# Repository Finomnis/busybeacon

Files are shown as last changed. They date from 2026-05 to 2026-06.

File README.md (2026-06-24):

# BusyBeacon

<p>
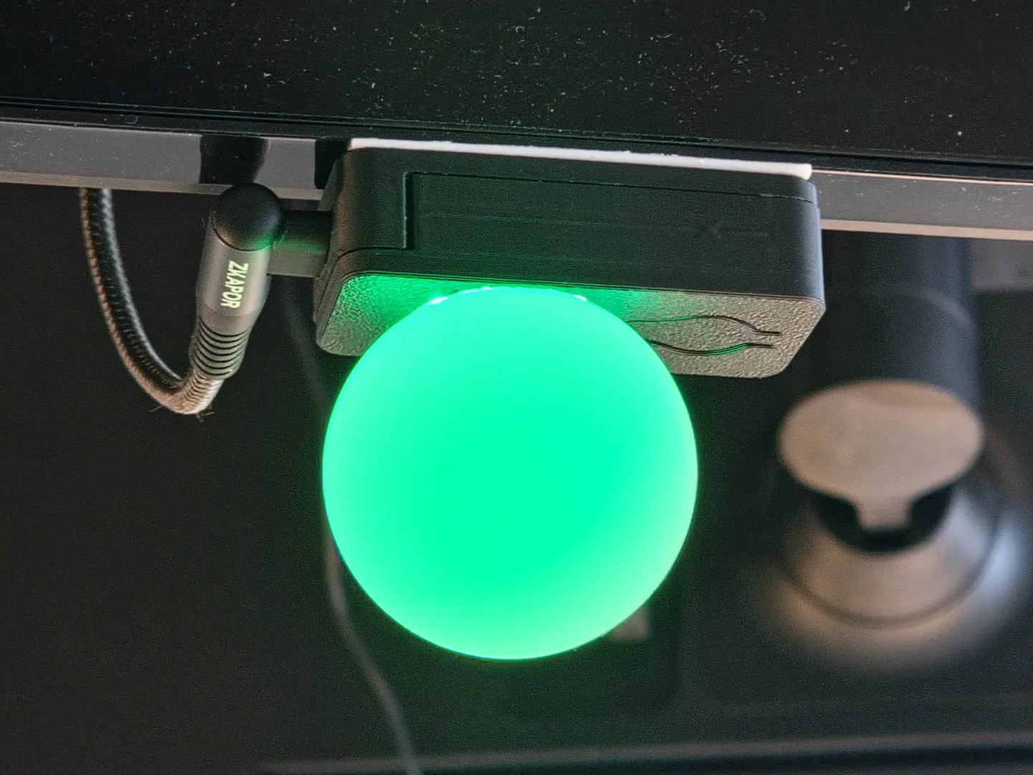
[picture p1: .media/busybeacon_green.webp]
Green

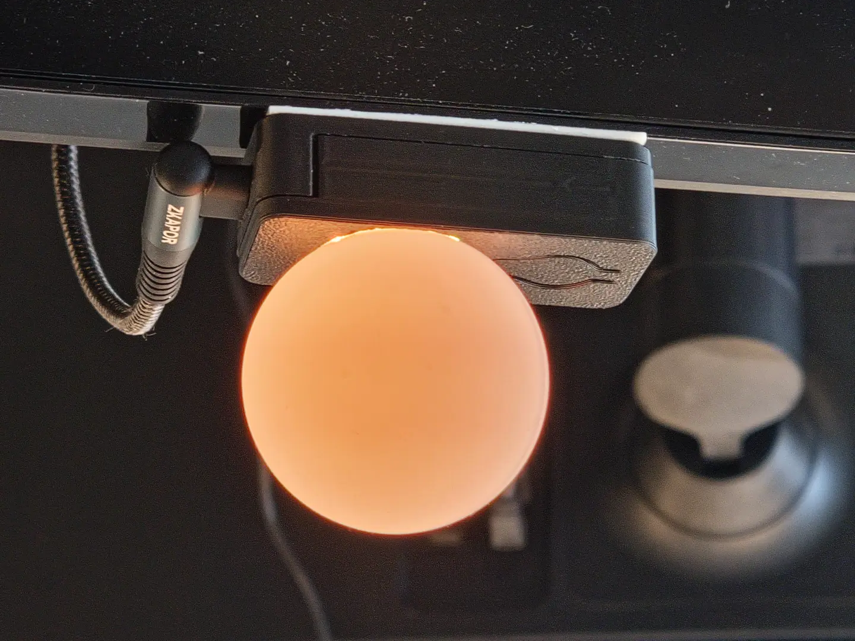
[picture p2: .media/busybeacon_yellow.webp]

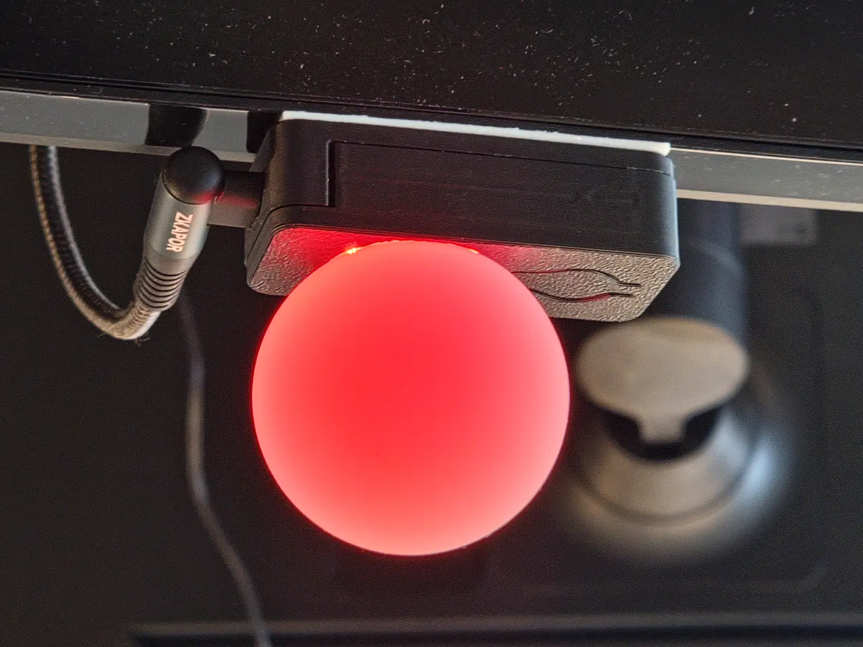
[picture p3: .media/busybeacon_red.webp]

</p>

An indicator that shows coworkers if you are busy.

Intended to be mounted to your monitor and updated whenever your current state changes.

### Color Meanings
- 🟢 **Green** - Can be talked to casually.
- 🟡 **Yellow** - Concentrated, only talk to about the current project.
- 🔴 **Red** - In the zone, do not talk to unless absolutely necessary.

### Controls

- Button:
    - Short press: Switch between colors
    - Long press: Turn on/off
- USB:
    - USB-HID device that can be used to set the color and switch it on/off
    - Turns off when the USB data connection stops (e.g. the PC is shut down).
        - Intended for monitors that power the device constantly, even if the PC is off

## Parts

- Table Tennis Ball as light diffusor
    - For best experience, choose seamless balls
- [Custom PCB](https://oshwlab.com/finomnis/busylight)
    - Orderable on JLCPCB for ~60 Euros / 10 PCBs
- 3D Printed Case
- LEDs: BTF-LIGHTING 144LEDs/m WS2812B
    - German Amazon: https://amzn.eu/d/06CgZDho
    - 3 LEDs needed per device

## Host software

The device can be controlled from the PC using the following programs:

- `busybeacon` - A tray icon with a menu
- `busybeacon-cli` - A command line tool

For Windows, precompiled executables can be found in the [releases page](https://github.com/Finomnis/busybeacon/releases).

- Copy `busybeacon.exe` into `%APPDATA%\Microsoft\Windows\Start Menu\Programs\Startup` to start it automatically on bootup.
- Once it runs, right click on taskbar -> `Taskbar settings` -> `Other system tray icons` -> `busybeacon.exe` -> `On` to show it in the taskbar

For Linux / MacOS, the `software` directory contains the source code
that can be compiled as usual:

```shell
cd software
cargo build --release
```

MacOS is currently untested.

## Firmware

The newest version can be found in the [releases page](https://github.com/Finomnis/busybeacon/releases).

The bootloader and firmware have to be installed once from the `.hex` files:

```shell
probe-rs download --binary-format hex --chip stm32u073cc --verify busybeacon.bootloader.hex
probe-rs download --binary-format hex --chip stm32u073cc --verify busybeacon.hex
```

Afterwards, the application can be updated via the `.dfu` file:

```shell
dfu-util --download busybeacon.dfu
```

If DFU flashing fails, enter bootloader recovery mode by keeping the button pressed while plugging in the device. It should then react to `dfu-util` again.

**NOTE:** It is normal that `dfu-util` ends with an error message like so:
```
Download        [=========================] 100%        90672 bytes
Download done.
dfu-util: unable to read DFU status after completion (LIBUSB_ERROR_IO)
```

This is a technical limitation that might get fixed in the future, but it's purely cosmetic.

## Build Instructions

1. Download the relevant files from the [releases page](https://github.com/Finomnis/busybeacon/releases).
2. Flash the PCB with the latest bootloader & firmware.
   - This requires a TC2050 adapter and a suitable probe.
   - For more information, see `Firmware` in this readme.
3. Print the case (top and bot)
4. Cut 3 LEDs from your BTF-LIGHTING 144LEDs/m WS2812B strip
5. Connect the PCB and the LEDs with three wires
6. Insert the PCB into the bottom case and glue the LED strip on the little
   shelf that will face the ball
7. Cut a hole in your tennis ball that fits the three LEDs
8. Glue the Ball on the Top case
9. Slide the case together

Then, plug the device into a USB-C port and you will see the ball light up green.

You can now control the ball using the button as described in the `Controls` section, or you can install the tray icon app to control it via a tray icon of your PC.

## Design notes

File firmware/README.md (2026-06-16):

# BusyBeacon Firmware

## Datasheets:

- [STM32U073CCU6 Datasheet](https://www.st.com/resource/en/datasheet/stm32u073cc.pdf)
- [STM32U0 Reference Manual](https://www.st.com/resource/en/reference_manual/rm0503-stm32u0-series-advanced-armbased-32bit-mcus-stmicroelectronics.pdf)

## Getting Started

Before getting started, you need Rust/Cargo installed.

See https://rustup.rs/.

### Further dependencies

- `cargo binstall` - Optional, if not desired replace `binstall` in the other dependencies with `install`

  ```shell
  cargo install cargo-binstall --locked
  ```

- `flip-link`

  ```shell
  cargo binstall flip-link
  ```

- `cargo objcopy`

  ```
  rustup component add llvm-tools
  cargo binstall cargo-binutils
  ```

- `probe-rs`

  ```
  cargo binstall probe-rs-tools
  ```

## Application

### Build

```shell
cargo build --release
```

### Build and flash

```shell
cargo program --release
```

### Generate hex

```shell
cargo objcopy --release -- -O ihex app.hex

# To flash:
probe-rs download --binary-format hex --chip stm32u073cc app.hex
```

### Generate dfu file

```shell
cargo objcopy --release -- -O binary app.dfu
# Add dfu suffix containing VID:PID to the image:
dfu-suffix --vid 1209 --pid d9d0 --add app.dfu

# To update:
sudo dfu-util --download app.dfu
```

*Note*: It is normal to get the following error at the end of the update.
This is currently a technical limitation, but it's purely cosmetic.

```text
...
Download done.
unable to read DFU status after completion (LIBUSB_ERROR_PIPE)
```

## Bootloader

### Build

```shell
cargo build -p busybeacon-bootloader --release
```

### Build and flash

```shell
cargo program -p busybeacon-bootloader --release
```

### Generate hex

```shell
cargo objcopy -p busybeacon-bootloader --release -- -O ihex bootloader.hex

# To flash:
probe-rs download --binary-format hex --chip stm32u073cc bootloader.hex
```

## Tests

### Execute tests on host

```shell
cargo test-host
```

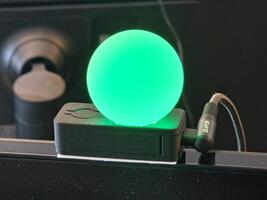
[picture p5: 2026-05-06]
.media/busybeacon_green_small.jpg

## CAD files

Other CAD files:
hardware/BusyBeaconCase_Bot.step
hardware/BusyBeaconCase_Top.step
hardware/BusyBeaconCase.f3z

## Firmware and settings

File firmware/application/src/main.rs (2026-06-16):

#![no_std]
#![no_main]

mod led_statemachine;
mod panic_handler;
mod uart_logger;
mod usb_utils;

use async_button_rtic::{Button, ButtonConfig, ButtonEvent};
use core::cell::RefCell;
use embassy_boot_stm32::{AlignedBuffer, BlockingFirmwareState, FirmwareUpdaterConfig};
use embassy_stm32::{
    Config, bind_interrupts, dma,
    exti::{self, ExtiInput},
    flash::{Flash, WRITE_SIZE},
    gpio::Pull,
    interrupt,
    mode::Async,
    peripherals,
    rcc::mux::Clk48sel,
    spi,
    spi::Spi,
    time::Hertz,
    usart, usb,
};
use embassy_usb::{
    UsbDevice,
    class::hid::{self, HidBootProtocol, HidReader, HidSubclass, HidWriter},
    msos,
};
use embassy_usb_dfu::application::{DfuAttributes, DfuState, usb_dfu};
use led_statemachine::{LedController, LedEvent};
use log::info;
use portable_atomic::AtomicU8;
use static_cell::ConstStaticCell;
use usb_utils::{
    DEVICE_INTERFACE_GUIDS, HidRequestHandler, USB_BCD_DEVICE_VERSION, UsbEventHandler,
};

bind_interrupts!(struct Irqs {
    DMA1_CHANNEL2_3 =>
        dma::InterruptHandler<peripherals::DMA1_CH2>,
        dma::InterruptHandler<peripherals::DMA1_CH3>;
    EXTI4_15 => exti::InterruptHandler<interrupt::typelevel::EXTI4_15>;
    USB_DRD_FS => usb::InterruptHandler<peripherals::USB>;
});

struct DfuHandler<'d, FLASH: embedded_storage::nor_flash::NorFlash> {
    firmware_state: BlockingFirmwareState<'d, FLASH>,
}

impl<FLASH: embedded_storage::nor_flash::NorFlash> embassy_usb_dfu::application::Handler
    for DfuHandler<'_, FLASH>
{
    fn enter_dfu(&mut self) {
        match self.firmware_state.mark_dfu() {
            Ok(()) => cortex_m::peripheral::SCB::sys_reset(),
            Err(_) => {
                log::error!("failed to mark DFU mode");
            }
        }
    }
}

static CONFIG_DESCRIPTOR: ConstStaticCell<[u8; 256]> = ConstStaticCell::new([0u8; 256]);
static BOS_DESCRIPTOR: ConstStaticCell<[u8; 256]> = ConstStaticCell::new([0u8; 256]);
static MSOS_DESCRIPTOR: ConstStaticCell<[u8; 1024]> = ConstStaticCell::new([0u8; 1024]);
static CONTROL_BUF: ConstStaticCell<[u8; 4096]> = ConstStaticCell::new([0u8; 4096]);
static MAGIC: ConstStaticCell<embassy_boot_stm32::AlignedBuffer<WRITE_SIZE>> =
    ConstStaticCell::new(AlignedBuffer([0; WRITE_SIZE]));

use rtic_monotonics::stm32::prelude::*;
stm32_tim2_monotonic!(Mono, 1_000_000);

type BlockingFlash = Flash<'static, embassy_stm32::flash::Blocking>;

const HID_REPORT_DESCRIPTOR: &[u8] = &[
    0x06, 0x00, 0xff, // Usage Page: vendor-defined 0xff00
    0x09, 0x01, // Usage: 1
    0xa1, 0x01, // Collection: Application
    //
    // Output report: 1 byte, values 0..3.
    0x85, 0x01, // Report ID 1
    0x09, 0x01, // Usage: busy state
    0x15, 0x00, // Logical min 0
    0x25, 0x03, // Logical max 3
    0x75, 0x08, // Report size 8 bits
    0x95, 0x01, // Report count 1
    0x91, 0x02, // Output: Data,Var,Abs
    //
    // Feature report: PC queries current LED state
    0x85, 0x02, // Report ID 2
    0x09, 0x02, //
    0x15, 0x00, //
    0x25, 0x03, //
    0x75, 0x08, //
    0x95, 0x01, //
    0xb1, 0x02, // Feature
    //
    // Input report: device pushes current LED state
    0x85, 0x03, // Report ID 3
    0x09, 0x03, //
    0x15, 0x00, //
    0x25, 0x03, //
    0x75, 0x08, //
    0x95, 0x01, //
    0x81, 0x02, // Input
    //
    0xc0, // End collection
];

static LED_STATE: AtomicU8 = AtomicU8::new(0);

#[rtic::app(
    device = ::embassy_stm32::pac,
    peripherals = false,
    dispatchers = [TIM15_LPTIM3, TIM16, TIM7_LPTIM2] // free IRQs used by RTIC for async software tasks
)]
mod app {

    use super::*;

    #[shared]
    struct Shared {
        led_event_sender: rtic_sync::channel::Sender<'static, LedEvent, 10>,
    }

    #[local]
    struct Local {
        led_controller: LedController,
        button: Button<ExtiInput<'static, Async>, Mono>,
        log_handler: uart_logger::UartLogHandler,
        usb_dev: UsbDevice<'static, usb::Driver<'static, peripherals::USB>>,
        hid_reader: HidReader<'static, usb::Driver<'static, peripherals::USB>, 8>,
        hid_writer: HidWriter<'static, usb::Driver<'static, peripherals::USB>, 8>,
        state_changed_writer: rtic_sync::signal::SignalWriter<'static, u8>,
        state_changed_reader: rtic_sync::signal::SignalReader<'static, u8>,
    }

    #[init(local = [
        flash: Option<embassy_sync::blocking_mutex::NoopMutex<RefCell<BlockingFlash>>> = None,
        dfu_state: Option<DfuState<DfuHandler<'static, embassy_embedded_hal::flash::partition::BlockingPartition<'static, embassy_sync::blocking_mutex::raw::NoopRawMutex, BlockingFlash>>>> = None,
        hid_state: Option<hid::State<'static>> = None,
        usb_event_handler: Option<UsbEventHandler> = None,
        hid_request_handler: HidRequestHandler = HidRequestHandler::new(),
    ])]
    fn init(mut cx: init::Context) -> (Shared, Local) {
        let mut config = Config::default();
        {
            use embassy_stm32::rcc::*;
            config.rcc.hsi = true;
            config.rcc.pll = Some(Pll {
                source: PllSource::HSI, // 16 MHz
                prediv: PllPreDiv::DIV1,
                mul: PllMul::MUL6, // 16 * 6 = 96 MHz
                divp: None,
                divq: None,
                divr: Some(PllRDiv::DIV2), // 96 / 2 = 48 MHz
            });
            config.rcc.sys = Sysclk::PLL1_R;
            config.rcc.hsi48 = Some(Hsi48Config {
                sync_from_usb: true,
            });
            config.rcc.mux.clk48sel = Clk48sel::HSI48;
        }

        let p = embassy_stm32::init(config);

        let tim2_hz = embassy_stm32::rcc::frequency::<embassy_stm32::peripherals::TIM2>().0;
        Mono::start(tim2_hz);

        let mut uart_config = usart::Config::default();
        uart_config.baudrate = 115200;
        let uart = usart::UartTx::new(p.USART2, p.PA2, p.DMA1_CH2, Irqs, uart_config).unwrap();
        let log_handler = uart_logger::init(uart);
        info!("init");

        let mut spi_config = spi::Config::default();
        spi_config.frequency = Hertz(3_000_000);
        spi_config.mode = spi::MODE_1;

        let spi = Spi::new_txonly(p.SPI1, p.PA1, p.PA7, p.DMA1_CH3, Irqs, spi_config);

        let button = ExtiInput::new(p.PA5, p.EXTI5, Pull::Up, Irqs);

        let button_config = ButtonConfig {
            double_click: 0.millis(),
            ..Default::default()
        };

        let button = Button::new(button, button_config);

        let flash = Flash::new_blocking(p.FLASH);
        let flash = embassy_sync::blocking_mutex::NoopMutex::new(RefCell::new(flash));
        let flash = cx.local.flash.insert(flash);

        let usb_driver = embassy_stm32::usb::Driver::new(p.USB, Irqs, p.PA12, p.PA11);

        let mut config = embassy_usb::Config::new(0x1209, 0xd9d0);
        config.manufacturer = Some("Finomnis");
        config.product = Some("BusyBeacon");
        config.serial_number = Some(embassy_stm32::uid::uid_hex());
        config.device_release = USB_BCD_DEVICE_VERSION;

        let firmware_updater_config = FirmwareUpdaterConfig::from_linkerfile_blocking(flash, flash);
        let magic = MAGIC.take();
        let mut firmware_state =
            BlockingFirmwareState::from_config(firmware_updater_config, &mut magic.0);
        firmware_state.mark_booted().expect("Failed to mark booted");

        let dfu_handler = DfuHandler { firmware_state };
        let dfu_state = DfuState::new(
            dfu_handler,
            DfuAttributes::CAN_DOWNLOAD | DfuAttributes::WILL_DETACH,
            embassy_time::Duration::from_millis(2500),
        );
        let dfu_state = cx.local.dfu_state.insert(dfu_state);

        let config_descriptor = CONFIG_DESCRIPTOR.take();
        let bos_descriptor = BOS_DESCRIPTOR.take();
        let msos_descriptor = MSOS_DESCRIPTOR.take();
        let control_buf = CONTROL_BUF.take();

        let mut builder = embassy_usb::Builder::new(
            usb_driver,
            config,
            config_descriptor,
            bos_descriptor,
            msos_descriptor,
            control_buf,
        );

        // --- HID busy-light interface ---
        let hid_state = cx.local.hid_state.insert(hid::State::new());

        let hid_config = hid::Config {
            report_descriptor: HID_REPORT_DESCRIPTOR,
            request_handler: Some(cx.local.hid_request_handler),
            poll_ms: 10,
            max_packet_size: 8,
            hid_subclass: HidSubclass::No,
            hid_boot_protocol: HidBootProtocol::None,
        };

        let (hid_reader, hid_writer) =
            hid::HidReaderWriter::<_, 8, 8>::new(&mut builder, hid_state, hid_config).split();
        let (state_changed_writer, state_changed_reader) = rtic_sync::make_signal!(u8);

        // We add MSOS headers so that the device automatically gets assigned the WinUSB driver on Windows.
        // Otherwise users need to do this manually using a tool like Zadig.
        //
        // It seems these always need to be at added at the device level for this to work and for
        // composite devices they also need to be added on the function level (as shown later).
        //
        builder.msos_descriptor(msos::windows_version::WIN8_1, 2);
        builder.msos_feature(msos::CompatibleIdFeatureDescriptor::new("WINUSB", ""));
        builder.msos_feature(msos::RegistryPropertyFeatureDescriptor::new(
            "DeviceInterfaceGUIDs",
            msos::PropertyData::RegMultiSz(DEVICE_INTERFACE_GUIDS),
        ));

        usb_dfu(&mut builder, dfu_state, |func| {
            // You likely don't have to add these function level headers if your USB device is not composite
            // (i.e. if your device does not expose another interface in addition to DFU)
            func.msos_feature(msos::CompatibleIdFeatureDescriptor::new("WINUSB", ""));
            func.msos_feature(msos::RegistryPropertyFeatureDescriptor::new(
                "DeviceInterfaceGUIDs",
                msos::PropertyData::RegMultiSz(DEVICE_INTERFACE_GUIDS),
            ));
        });

        let (led_event_sender, led_event_receiver) = rtic_sync::make_channel!(LedEvent, 10);
        let led_controller = LedController::new(spi, led_event_receiver);

        let usb_event_handler = cx
            .local
            .usb_event_handler
            .insert(UsbEventHandler::new(led_event_sender.clone()));

        builder.handler(usb_event_handler);

        let usb_dev = builder.build();

        // Set the ARM SLEEPONEXIT bit to go to sleep after handling interrupts
        // See https://developer.arm.com/docs/100737/0100/power-management/sleep-mode/sleep-on-exit-bit
        cx.core.SCB.set_sleeponexit();

        led_control_loop::spawn().unwrap();
        log_handler::spawn().unwrap();
        usb_handler::spawn().unwrap();
        usb_hid_reader::spawn().unwrap();
        usb_hid_writer::spawn().unwrap();
        button_handler::spawn().unwrap();

        (
            Shared { led_event_sender },
            Local {
                led_controller,
                button,
                log_handler,
                usb_dev,
                hid_reader,
                hid_writer,
                state_changed_writer,
                state_changed_reader,
            },
        )
    }

    #[idle]
    fn idle(_cx: idle::Context) -> ! {
        info!("idle");
        loop {
            // Wait For Interrupt is used instead of a busy-wait loop
            // to allow MCU to sleep between interrupts
            // https://developer.arm.com/documentation/ddi0406/c/Application-Level-Architecture/Instruction-Details/Alphabetical-list-of-instructions/WFI
            rtic::export::wfi()
        }
    }

    #[task(priority = 1, local = [log_handler])]
    async fn log_handler(ctx: log_handler::Context) {
        let log_handler = ctx.local.log_handler;
        log_handler.run().await;
    }

    #[task(priority = 2, local = [usb_dev])]
    async fn usb_handler(ctx: usb_handler::Context) {
        let usb_dev = ctx.local.usb_dev;
        usb_dev.run().await;
    }

    #[task(priority = 2, local = [hid_writer, state_changed_reader])]
    async fn usb_hid_writer(ctx: usb_hid_writer::Context) {
        let hid = ctx.local.hid_writer;
        let state_receiver = ctx.local.state_changed_reader;

        loop {
            let state = state_receiver.wait().await;
            let _ = hid.write(&[3, state]).await;
        }
    }

    #[task(priority = 2, local = [hid_reader], shared = [&led_event_sender])]
    async fn usb_hid_reader(ctx: usb_hid_reader::Context) {
        let hid = ctx.local.hid_reader;
        let mut event_sender = ctx.shared.led_event_sender.clone();

        let hid_report = &mut [0u8; 8];

        loop {
            hid.ready().await;
            if let Ok(len) = hid.read(hid_report).await
                && len >= 2
                && hid_report[0] == 1
            {
                match hid_report[1] {
                    0 => {
                        let _ = event_sender.send(LedEvent::Off).await;
                    }
                    1 => {
                        let _ = event_sender.send(LedEvent::Green).await;
                    }
                    2 => {
                        let _ = event_sender.send(LedEvent::Yellow).await;
                    }
                    3 => {
                        let _ = event_sender.send(LedEvent::Red).await;
                    }
                    _ => (),
                }
            }
        }
    }

    #[task(priority = 2, local = [button], shared = [&led_event_sender])]
    async fn button_handler(ctx: button_handler::Context) {
        let button = ctx.local.button;
        let mut event_sender = ctx.shared.led_event_sender.clone();

        loop {
            match button.update().await {
                ButtonEvent::ShortPress { count: _ } => {
                    let _ = event_sender.send(LedEvent::ShortPress).await;
                }
                ButtonEvent::LongPress => {
                    let _ = event_sender.send(LedEvent::LongPress).await;
                }
            }
        }
    }

    #[task(priority = 3, local = [led_controller, state_changed_writer])]
    async fn led_control_loop(ctx: led_control_loop::Context) {
        ctx.local
            .led_controller
            .run(ctx.local.state_changed_writer)
            .await;
    }
}

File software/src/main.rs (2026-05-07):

const VID: u16 = 0x1209;
const PID: u16 = 0xd9d0;

fn main() {
    let api = hidapi::HidApi::new().unwrap();

    let mut devices = api
        .device_list()
        .filter(|val| val.product_id() == PID && val.vendor_id() == VID);

    let device = devices.next().unwrap().open_device(&api).unwrap();

    device.write(&[0x00, 0x02]).unwrap();
}

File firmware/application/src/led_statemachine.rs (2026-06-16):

use core::sync::atomic::Ordering;

use embassy_stm32::{
    mode::Async,
    spi::{self, Spi},
};

#[derive(Debug)]
pub enum LedEvent {
    Red,
    Yellow,
    Green,
    Off,
    EnterSleep,
    ExitSleep,
    ShortPress,
    LongPress,
}

const NUM_LEDS: usize = 5;
const COLORS: [(u8, u8, u8); 3] = [(0, 255, 0), (255, 100, 0), (255, 0, 0)];
const OFF_COLOR: (u8, u8, u8) = (0, 0, 0);

pub struct LedController {
    spi: Spi<'static, Async, spi::mode::Master>,
    events: rtic_sync::channel::Receiver<'static, LedEvent, 10>,
}

impl LedController {
    pub fn new(
        spi: Spi<'static, Async, spi::mode::Master>,
        events: rtic_sync::channel::Receiver<'static, LedEvent, 10>,
    ) -> Self {
        Self { spi, events }
    }

    async fn set_led(&mut self, color: (u8, u8, u8)) {
        log::info!("Color: {:?}", color);
        let mut data = [0u8; busybeacon_core::neopixel::buffer_size(NUM_LEDS)];
        let data = busybeacon_core::neopixel::fill_with_color(&mut data, color);
        self.spi.write(data).await.unwrap();
    }

    pub async fn run(&mut self, state_changed: &mut rtic_sync::signal::SignalWriter<'static, u8>) {
        log::info!("led_control_loop");

        let mut enabled = true;
        let mut color_id = 0u8;
        let mut sleep = false;

        loop {
            if enabled
                && !sleep
                && let Some(&color) = COLORS.get(usize::from(color_id))
            {
                crate::LED_STATE.store(1 + color_id, Ordering::Relaxed);
                state_changed.write(1 + color_id);
                self.set_led(color).await;
            } else {
                crate::LED_STATE.store(0, Ordering::Relaxed);
                state_changed.write(0);
                self.set_led(OFF_COLOR).await;
            }

            let event = self.events.recv().await.unwrap();

            match event {
                LedEvent::Red => {
                    enabled = true;
                    sleep = false;
                    color_id = 2;
                }
                LedEvent::Yellow => {
                    enabled = true;
                    sleep = false;
                    color_id = 1;
                }
                LedEvent::Green => {
                    enabled = true;
                    sleep = false;
                    color_id = 0;
                }
                LedEvent::Off => {
                    enabled = false;
                }
                LedEvent::EnterSleep => {
                    sleep = true;
                }
                LedEvent::ExitSleep => {
                    sleep = false;
                }
                LedEvent::ShortPress => {
                    if sleep {
                        sleep = false;
                    } else if enabled {
                        color_id = (color_id + 1) % (COLORS.len() as u8);
                    }
                }
                LedEvent::LongPress => {
                    if sleep {
                        sleep = false;
                        enabled = true;
                    } else {
                        enabled = !enabled;
                    }
                }
            }
        }
    }
}

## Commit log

2026-05-05 Add uart logging
2026-05-14 Add current color querying (#18)
2026-05-14 Rework software for input reports (#21)
    [busylight.rs, main.rs]
2026-05-15 Refactor USB-HID to use numbered reports (#22)
    Also, fix missing dependency on windows
    [main.rs]
2026-05-18 Modify download commands in README for STM32 chip
    Updated commands to include chip specification for STM32.
2026-06-16 Rename busylight to busybeacon to avoid trademark violation (#24)
    [led_statemachine.rs, main.rs, uart_logger.rs]
2026-06-23 Add hardware files
    [BusyBeaconCase.f3z, BusyBeaconCase_Bot.step, BusyBeaconCase_Top.step]
